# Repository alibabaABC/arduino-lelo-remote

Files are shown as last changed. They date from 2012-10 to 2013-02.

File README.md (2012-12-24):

arduino-lelo-remote
===================

This project is an Arduino-based remote control for the radio-controlled Lelo vibrators. This speaks the RF protocol used by the Lyla vibrator, which may also be used by other products from Lelo. 

Library
-------

The "LeloRemote" directory is an Arduino library. It comes with a couple very simple examples. To use this in your own projects, just copy the whole thing into your Arduino "libraries" folder.

The library requires a CC2500 radio chip. Breakout boards for this chip are plentiful on eBay from a variety of manufacturers.

Take care that this is a 3.3v chip! If possible, use an Arduino variant with a 3.3v supply. If you must use a 5v Arduino, you _must_ power the CC2500 off a 3.3v regulator. If you're using an Arduino Uno, for example, there's already a 3.3v output pin that will work fine. To protect the 3.3v inputs on the CC2500, use 1K resistors in series with the MOSI, SCK, and SS pins.

Vibeam Sonar Remote, version 01
-------------------------------

The Vibeam project (Vibrator + Beam) is a wireless hands-free vibrator controller based on the Parallax Ping sonar sensor. Source code and design files are in the "vibeam01" folder.

This project is described in more detail at: http://scanlime.org/2012/11/hacking-my-vagina/

It uses an Arduino Pro Mini and the LeloRemote Arduino library. Additionally, it needs:

 - A portable source of regulated 5V power. I used a cheap USB phone charger battery
 - The Parallax Ping sonar sensor
 - A 4-digit serial LED module from SparkFun
 - The CC2500 radio

I designed a 3D printable housing, designed to be printable on a Makerbot or similar printer. The original design source files for Blender are here, as are ready-to-print STL meshes.

NOTE: The 4-digit serial LED module has been discontinued. It is optional, but this makes it hard to exactly reproduce the original project unless you have a stock of these old modules.

Vibeam Sonar Remote, version 02
-------------------------------

This revision of the design is intended to reduce cost and remove dependencies on obsolete parts. This version consists of:

 - SparkFun COM-11442 serial LED module with a built-in Arduino-compatible ATmega328: https://www.sparkfun.com/products/11442
 - A cheaper sonar sensor, HC-SR04, available from multiple vendors on eBay.
 - An amplified CC2500 radio module, XL2500-D03, also available from eBay.
 - The same 5V USB battery pack used in version 01.

About
-----

Written by Micah Elizabeth Scott. Everything here is released under the CC-BY-SA license.

http://creativecommons.org/licenses/by-sa/2.0/

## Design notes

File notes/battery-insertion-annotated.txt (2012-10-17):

0000
300F            SRES strobe: Soft reset

0B0F 0A0F       FSCTRL1     IF frequency of 253.9 kHz
0C0F 000F       FSCTRL0     No frequency offset (default)
0D0F 5D0F       FREQ2       FREQ = 0x5d13b1 = 2420 MHz
0E0F 130F       FREQ1
0F0F B10F       FREQ0
100F 2D0F       MDMCFG4     CHANBW = 541.666 kHz
110F 3B0F       MDMCFG3     DRATE = 249.94 kBaud
120F 730F       MDMCFG2     MSK modulation, 30/32 sync word bits
130F 220F       MDMCFG1     FEC disabled, 2 preamble bytes
140F F80F       MDMCFG0     CHANSPC = 199.951 kHz
0A0F 000F       CHANNR      Channel number 0 (default)
150F 000F       DEVIATN     MSK phase change duty cycle
210F B60F       FREND1
220F 100F       FREND0
180F 180F       MCSM0       Auto calibrate, Poweron timeout
190F 1D0F       FOCCFG
1A0F 1C0F       BSCFG
1B0F C70F       AGCTRL2
1C0F 000F       AGCTRL1
1D0F B00F       AGCTRL0
230F EA0F       FSCAL3
240F 0A0F       FSCAL2
250F 000F       FSCAL1
260F 110F       FSCAL0
290F 590F       FSTEST      Test only (default)
2C0F 880F       TEST2       Test settings (default)
2D0F 310F       TEST1       Test settings (default)
2E0F 0B0F       TEST0       Test settings (default)
000F 290F       IOCFG2      GDO2 used as CHIP_RDYn (default)
020F 060F       IOCFG0      GDO0 used as sync
070F 0A0F       PKTCTRL1    Addr check, broadcast, CRC autoflush
080F 040F       PKTCTRL0    No whitening, normal TX/RX mode, CRC on
090F 010F       ADDR        Device address 0x01
060F 090F       PKTLEN      Using 9-byte packet

7E0F FF0F FF0F FF0F FF0F FF0F FF0F FF0F FF0F 
                PATABLE     Maximum output power

3A0F            SFRX        strobe: flush RX fifo
3B0F            SFTX        strobe: flush TX fifo
360F            SIDLE
360F            SIDLE
390F            SPWD        strobe: Enter power-down mode

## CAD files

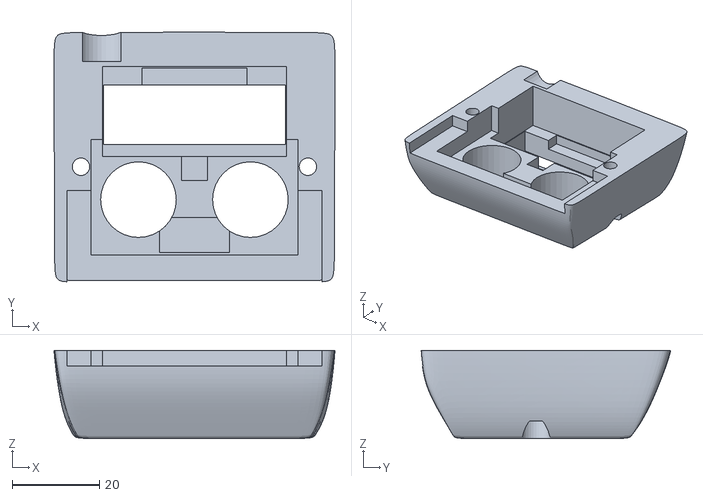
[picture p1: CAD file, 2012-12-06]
vibeam01/plastics/vibeam-top.stl
64.4 x 57.2 x 20.2

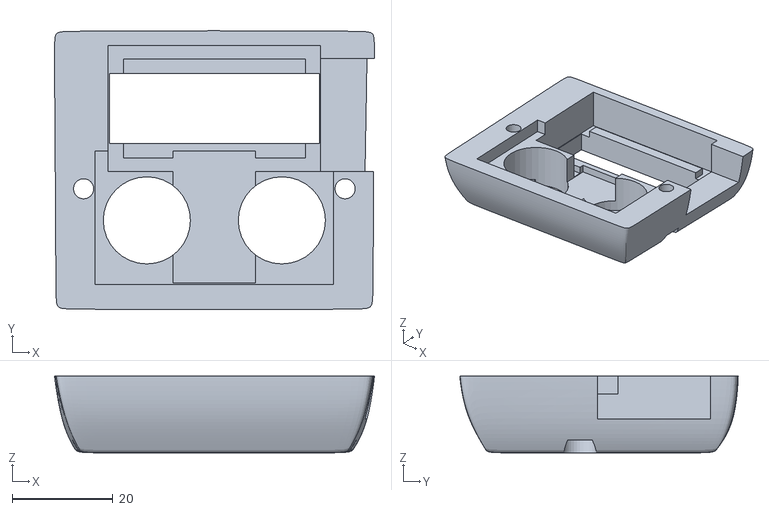
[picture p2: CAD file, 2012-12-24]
vibeam02/plastics/vibeam02-top.stl
63.6 x 55.4 x 15.3

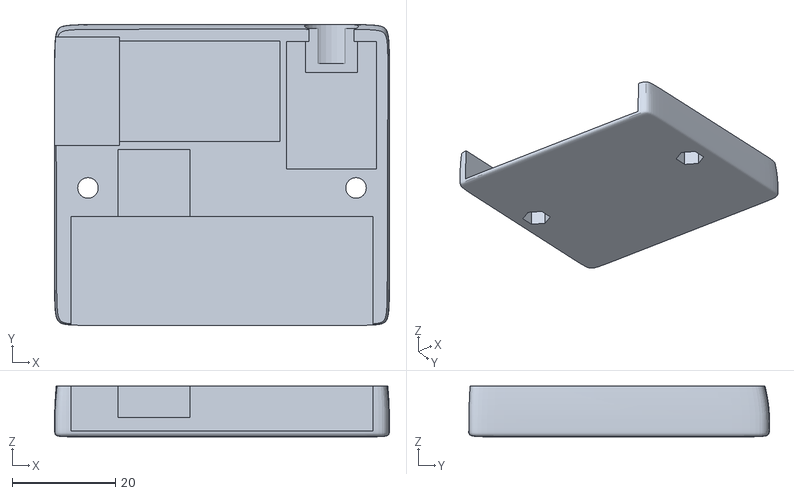
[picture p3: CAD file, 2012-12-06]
vibeam01/plastics/vibeam-bottom.stl
65.0 x 58.4 x 9.87

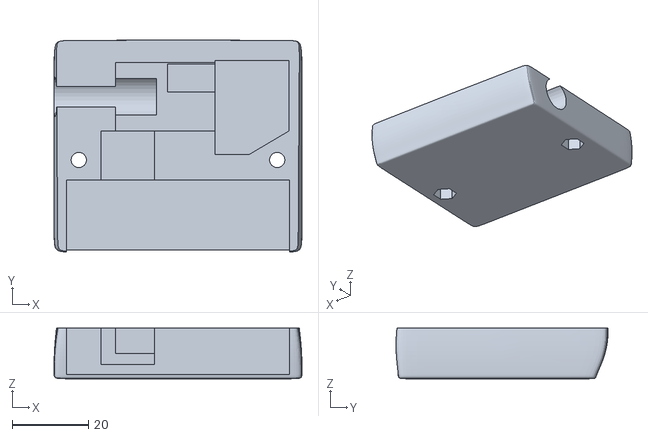
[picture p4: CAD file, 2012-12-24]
vibeam02/plastics/vibeam02-bottom.stl
65.0 x 55.6 x 13.3

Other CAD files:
vibeam02/plastics/vibeam.blend

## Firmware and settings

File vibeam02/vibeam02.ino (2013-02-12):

/*
 * Arduino sketch for version of the ViBeam remote.
 *
 * This uses the SparkFun serial 7-segment board (COM-11442), and it runs
 * entirely on the LED module's built-in ATmega328.
 *
 * Dependencies:
 *   - S7S Arduino add-on: https://github.com/sparkfun/Serial7SegmentDisplay
 *   - SevSeg library: https://github.com/sparkfun/SevSeg
 *
 * Micah Elizabeth Scott <beth@scanlime.org>
 * http://creativecommons.org/licenses/by-sa/2.0/
 */

#include <SevSeg.h>
#include <SPI.h>
#include <LeloRemote.h>
#include "RunningMedian.h"


/****************************************************************************
 ****************************************************************************/

/*
 * LED module abstraction, compatible with the SparkFun COM-11442.
 */

class LEDModule
{
  SevSeg display;
  char string[5];

public:
  int power;
  char mode;
  bool echoIndicator;

  void update()
  {
    /*
     * We use the right three digits for a power level, in decimal.
     * The left digit is a mode indicator, currently unused.
     * The first period is used to indicate the presence of a good Sonar echo. 
     */
    
    string[0] = mode;
    string[1] = power < 100  ? 'x' : (power / 100) % 10;
    string[2] = power < 10   ? 'x' : (power / 10) % 10;
    string[3] = power % 10;
    string[4] = 0;

    display.DisplayString(string, echoIndicator);
  }

  void setup()
  {
    display.Begin(COMMON_ANODE, 4, 16, 17, 3, 4, 2, 9, 8, 14, 6, A1, 23, 7, 5, 22, 6, 7);
    display.SetBrightness(100);

    power = 0;
    mode = 'x';
    echoIndicator = false;

    update();
  }    
};


/*
 * HC-SR04 sonar sensor, with a median filter for rejecting noise and outliers.
 */

class SonarModule
{
  static const int txPin = A4;
  static const int rxPin = A5;

  RunningMedian <unsigned long, 4> filter;
  bool tapState, prevTapState;

public:
  static const int LIMIT = 5000;
  static const int TAP = 200;
  static const int NEAR = 500;
  static const int FAR = 3000;

  bool measure(unsigned long &result)
  {
    // Take one measurement, and add it to the buffer.

    pinMode(txPin, OUTPUT);
    pinMode(rxPin, INPUT);

    digitalWrite(txPin, LOW);
    delayMicroseconds(2);
    digitalWrite(txPin, HIGH);
    delayMicroseconds(10);
    digitalWrite(txPin, LOW);

    // Listen for an echo, with timeout
    unsigned long echo = pulseIn(rxPin, HIGH, LIMIT);

    if (!echo)
      echo = LIMIT;

    // Update the filter
    filter.add(echo);
    bool okay = filter.getMedian(result) == filter.OK && result < LIMIT;

    // Detect 'tap' gesture, with hysteresis.
    prevTapState = tapState;
    tapState = result < (tapState ? NEAR : TAP);

    return okay;
  }

  bool tapped()
  {
    // Was a tap detected on the last measure()?
    return tapState && !prevTapState;
  }
};


/****************************************************************************
 ****************************************************************************/

LeloRemote remote;
LEDModule led;
SonarModule sonar;

void setup()
{
  Serial.begin(9600);
  led.setup();
  SPI.begin();
  remote.reset();
}

void sonarLoop()
{
  // At every loop iteration, take a sonar measurement and update the filter
  unsigned long range;
  led.echoIndicator = sonar.measure(range);

  // Change modes when the sensor is "tapped" by bringing the hand very close momentarily.
  if (sonar.tapped()) {
    led.mode = (led.mode == 'x') ? 'L' : 'x';
  }

  // In (L)ock mode, the power level only changes when a good sonar signal exists.
  if (led.mode != 'L' || led.echoIndicator) {
    // Calculate new power level
    led.power = constrain(map(range, sonar.FAR, sonar.NEAR, 0, remote.MAX_POWER), 0, remote.MAX_POWER);
  }
}

void loop()
{
  if (Serial.available()) {
    // Serial port puts us in Remote mode
    led.mode = 'R';
    led.echoIndicator = false;
    led.power = Serial.read();
 
    // Send back a flow control token
    Serial.write(0x01);

  } else if (led.mode != 'R') {
    // If we aren't in remote mode, control is via sonar.
    sonarLoop();
  }

  remote.txMotorPower(led.power);

  /* We need to rate limit our radio transmissions and our sonar pings,
   * since both the vibrator and sonar module will behave badly if we
   * spam them too quickly. Update LED while we wait.
   */
  static unsigned long deadline;
  for (;;) {
    unsigned long time = millis();
    if (time > deadline) {
      deadline += 30;
      break;
    }

    led.update();
  }
}

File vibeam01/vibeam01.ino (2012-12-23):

/*
 * Arduino sketch for the original ViBeam remote, as described here:
 * http://scanlime.org/2012/11/hacking-my-vagina/
 *
 * Micah Elizabeth Scott <beth@scanlime.org>
 * http://creativecommons.org/licenses/by-sa/2.0/
 */

#include <SPI.h>
#include <LeloRemote.h>
#include <SoftwareSerial.h>
#include "RunningMedian.h"

/****************************************************************************
 ****************************************************************************/


/*
 * Simple driver for a SparkFun COM-097565 serial LED module.
 */

class LEDModule
{
  SoftwareSerial serial;

public:
  LEDModule(int dummyPin, int txPin) :
    serial(dummyPin, txPin) {}

  int power;
  char mode;
  bool echoIndicator;

  void update()
  {
    /*
     * We use the right three digits for a power level, in decimal.
     * The left digit is a mode indicator, currently unused.
     * The first period is used to indicate the presence of a good Sonar echo. 
     */

    serial.write(0x77);    // Decimal point command    
    serial.write(echoIndicator);
  
    serial.write(mode);
    serial.write(power < 100  ? 'x' : (power / 100) % 10);
    serial.write(power < 10   ? 'x' : (power / 10) % 10);
    serial.write(power % 10);
  }

  void setup()
  {
    serial.begin(9600);

    power = 0;
    mode = 'x';
    echoIndicator = false;

    serial.write(0x76);    // Soft reset, home cursor
    update();
  }    
};


/*
 * Ping sonar sensor, with a median filter for rejecting noise and outliers.
 */

class PingModule
{
  int pin;

  RunningMedian <unsigned long, 16> filter;
  bool tapState, prevTapState;

public:
  static const int LIMIT = 5000;
  static const int TAP = 200;
  static const int NEAR = 500;
  static const int FAR = 3000;

  PingModule(int pin) : pin(pin) {}

  bool measure(unsigned long &result)
  {
    // Take one measurement, and add it to the buffer.
    // Based on http://arduino.cc/en/Tutorial/Ping

    pinMode(pin, OUTPUT);       // Switch signalpin to output
    digitalWrite(pin, LOW);     // Send low pulse
    delayMicroseconds(2);       // Wait for 2 microseconds
    digitalWrite(pin, HIGH);    // Send high pulse
    delayMicroseconds(5);       // Wait for 5 microseconds
    digitalWrite(pin, LOW);     // Holdoff
    pinMode(pin, INPUT);        // Switch signalpin to input
    digitalWrite(pin, HIGH);    // Turn on pullup resistor

    // Listen for an echo, with timeout
    unsigned long echo;
    echo = pulseIn(pin, HIGH, LIMIT);
    if (!echo)
      echo = LIMIT;

    // Update the filter
    filter.add(echo);
    bool okay = filter.getMedian(result) == filter.OK && result < LIMIT;

    // Detect 'tap' gesture, with hysteresis.
    prevTapState = tapState;
    tapState = result < (tapState ? NEAR : TAP);

    return okay;
  }

  bool tapped()
  {
    // Was a tap detected on the last measure()?
    return tapState && !prevTapState;
  }
};


/****************************************************************************
 ****************************************************************************/

LeloRemote remote;
LEDModule led(2, 3);
PingModule ping(4);

void setup()
{
  Serial.begin(9600);
  led.setup();
  SPI.begin();
  remote.reset();
}

void loop()
{
  // At every loop iteration, take a sonar measurement and update the filter
  unsigned long range;
  led.echoIndicator = ping.measure(range);

  // Change modes when the sensor is "tapped" by bringing the hand very close momentarily.
  if (ping.tapped()) {
    led.mode = (led.mode == 'x') ? 'L' : 'x';
  }

  // We only want to send radio packets at about 80 Hz, so rate-limit the rest of our calculations.
  static unsigned long deadline;
  unsigned long time = millis();
  if (time <= deadline)
    return;
  deadline = time + 1000 / 80;

  // In (L)ock mode, the power level only changes when a good sonar signal exists.
  if (led.mode != 'L' || led.echoIndicator) {
    // Calculate new power level
    led.power = constrain(map(range, ping.FAR, ping.NEAR, 0, remote.MAX_POWER), 0, remote.MAX_POWER);
  }

  // Send radio packet first, so it gets the lowest latency
  remote.txMotorPower(led.power);
  
  // Update lower-priority outputs
  led.update();
}

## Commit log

2012-10-17 The Arduino IDE likes subdirectories, okay.
2012-10-17 Sketch: Control motor power with analog input
2012-10-18 LED display, analog input hysteresis
2012-11-21 Reorganize LeloRemote to be a proper Arduino library
2012-11-21 Adding CAD files for plastics
    [vibeam-bottom.stl, vibeam-top.stl, vibeam.blend]
2012-11-21 Median filtering & Lock mode
2012-12-05 Bottom plastic: Move Arduino farther inward
    This should keep the serial pins from sticking out. Not yet tested.
    [vibeam-bottom.stl, vibeam.blend]
2012-12-06 Minor plastics change, account for larger Rev 2 Ping board
    The new Ping boards I just got in the mail are a little taller and much thicker. This change adds all the room I can comfortably give it. Hopefully that's enough.
    [vibeam-bottom.stl, vibeam-top.stl, vibeam.blend]
2012-12-06 The new Ping sensor is *much* thicker.
    I measured again, and it needs a solid 4mm of vertical space to avoid hitting the battery pack. This change shouldn't affect the bottom half at all, but the top is now about 2.5mm taller. I switched to M3x25 screws, and changed the shape of the top face slightly to give the screw holes a good place to sit.
    [vibeam-bottom.stl, vibeam-top.stl, vibeam.blend]
2012-12-23 Make room for a second major revision of vibeam
    [vibeam-bottom.stl, vibeam-top.stl, vibeam.blend]
2012-12-23 Arduino doesn't like underscores, blah.
    [vibeam-bottom.stl, vibeam-top.stl, vibeam.blend]
2012-12-24 Rough but functional firmware for vibeam02
    [vibeam.blend]
2012-12-24 First plausibly-correct version of vibeam02 plastics
    [vibeam.blend, vibeam02-bottom.stl, vibeam02-top.stl]
2013-02-12 Flow control for serial remote
2019-06-22 fix for gcc-avr version 4.7.1+
    https://github.com/scanlime/arduino-lelo-remote/issues/1
